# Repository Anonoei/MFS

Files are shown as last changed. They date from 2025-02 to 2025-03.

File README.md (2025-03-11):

# MFS
 Modular Filament Shelf

 

## Features
 - Expandable, just print more sides
 - Optionally secured with bolts
 - Fits spools and spool boxes

## BOM (per full side)
 All hardware is optional (except rods), and helps secure the pieces together
- 4x 5/16" rods, length by preference, designed around 1000mm
- 18x M3 heatsets
- 8x M3 nuts
- An M3 bolt for each fastner (26x)
- Printed Parts
  - Thin
    - [foot_x2](https://raw.githubusercontent.com/Anonoei/MFS/refs/heads/main/STLs/MFS-thin_foot_x2.stl)
    - [horizontal-left_x2](https://raw.githubusercontent.com/Anonoei/MFS/refs/heads/main/STLs/MFS-thin_horizontal-joint_left_x2.stl)
    - [horizontal-right_x2](https://raw.githubusercontent.com/Anonoei/MFS/refs/heads/main/STLs/MFS-thin_horizontal-joint_right_x2.stl)
    - [vertical-bottom_x2](https://raw.githubusercontent.com/Anonoei/MFS/refs/heads/main/STLs/MFS-thin_vertical-joint_bottom_x2.stl)
    - [vertical-top_x2](https://raw.githubusercontent.com/Anonoei/MFS/refs/heads/main/STLs/MFS-thin_vertical-joint_top_x2.stl)
    - [rod-joint_x2](https://raw.githubusercontent.com/Anonoei/MFS/refs/heads/main/STLs/MFS-thin_rod-joint_x4.stl)
  - Normal
    - [foot_x2](https://raw.githubusercontent.com/Anonoei/MFS/refs/heads/main/STLs/MFS_foot_x2.stl)
    - [horizontal-left_x2](https://raw.githubusercontent.com/Anonoei/MFS/refs/heads/main/STLs/MFS_horizontal-joint_left_x2.stl)
    - [horizontal-right_x2](https://raw.githubusercontent.com/Anonoei/MFS/refs/heads/main/STLs/MFS_horizontal-joint_right_x2.stl)
    - [vertical-bottom_x2](https://raw.githubusercontent.com/Anonoei/MFS/refs/heads/main/STLs/MFS_vertical-joint_bottom_x2.stl)
    - [vertical-top_x2](https://raw.githubusercontent.com/Anonoei/MFS/refs/heads/main/STLs/MFS_vertical-joint_top_x2.stl)
    - [rod-joint_x2](https://raw.githubusercontent.com/Anonoei/MFS/refs/heads/main/STLs/MFS_rod-joint_x4.stl)

### Breakdown
 - M3 heatsets (voron spec)
   - 18x total
     - rod-joint (x4)
       - 2x vertical -> rod-joint
       - 2x horizontal -> rod-joint
     - rod-joint foot (x2)
       - 2x foot -> rod-joint
     - horizontal (x2)
       - 1x horizontal left -> right
 - M3 nuts
   - 8x total
     - per rod (x4)
       - 2x, rod-joint -> rod

## Assembly
 The file number at the end indicates quantity for **one** shelf side, with two heights
 - `rod-joint` (x4): Corner pieces that also connect the `vertical-joint` and `horizontal-joint`
   - Each piece that connects to the `rod-joints` can be secured with 2x M3 bolts, and 2x M3 heatsets
   - Inside the slot, M3 nuts can be pressed in to use a bolt to secure the rod
     - there are 2x holes to allow two rods to be inserted and the shelf expanded
 - `vertical-joint` [top & bottom] (x2): Connects `rod-joints` vertically
   - `top` (1x female 1x male slot) can take 2x heatsets to lock it to bottom
   - Both are are secured using M3 bolts to M3 heatsets on `rod-joint`
 - `horizontal-joint` [left & right] (x2): Connects `rod-joints` horizontally
   - `right` (2x male) can take 1x heatset to lock it to left
   - Both are secured using M3 bolts to M3 heatsets on `rod-joint`
 - `foot` (x2): Bottom piece to ensure open spools don't touch the ground
   - Each foot is secured using M3 bolts to M3 heatsets on `rod-joint`

## Print settings
 - Layer height: 0.2
 - Nozzle: 0.4
 - Material: PLA

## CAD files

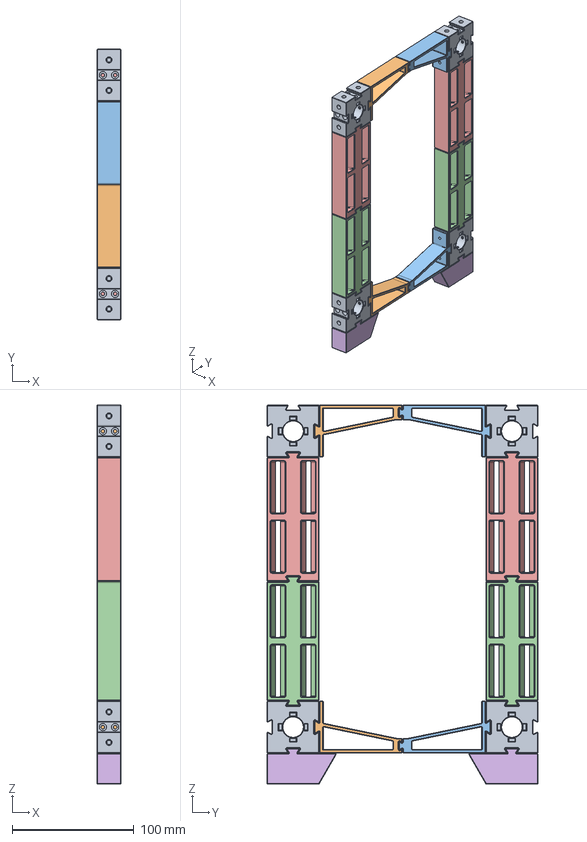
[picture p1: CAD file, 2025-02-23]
CAD/MFS-thin Side.step
20.0 x 222.8 x 311.8 mm
Rod Joint x 4
Horizontal Joint x 2
Vertical Joint x 2
Feet x 2

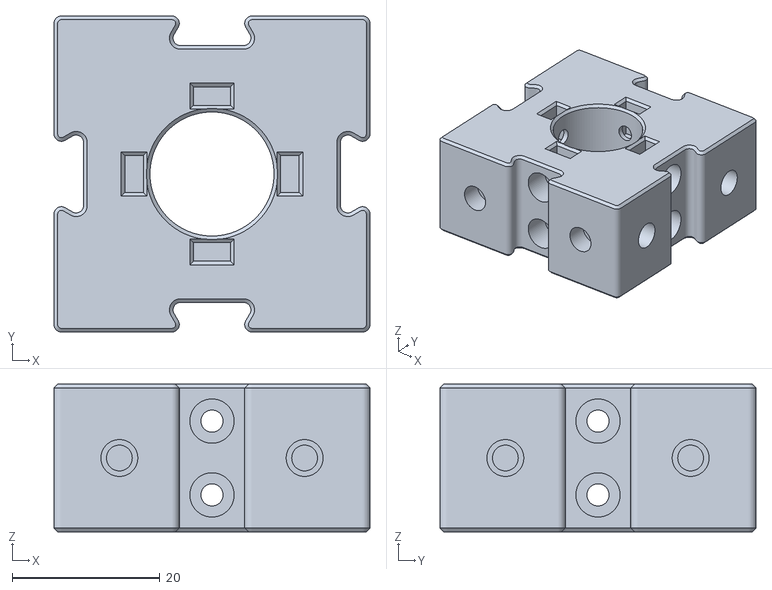
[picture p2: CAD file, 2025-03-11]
STLs/MFS-thin_rod-joint_x4.stl
42.8 x 42.8 x 20.0

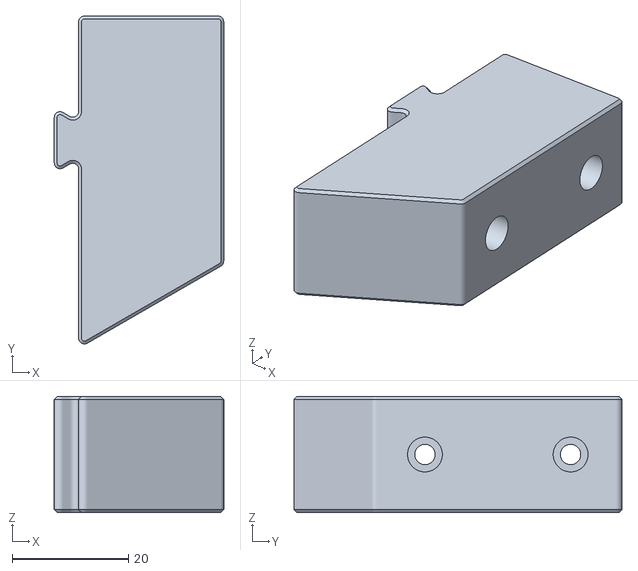
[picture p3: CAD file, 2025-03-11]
STLs/MFS-thin_foot_x2.stl
29.2 x 56.5 x 20.0

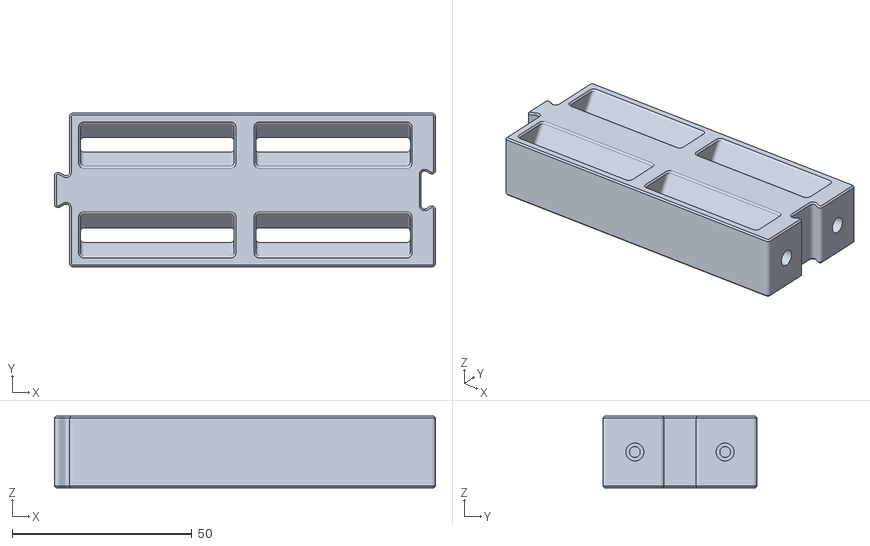
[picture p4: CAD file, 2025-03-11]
STLs/MFS-thin_vertical-joint_top_x2.stl
105.9 x 42.8 x 20.0

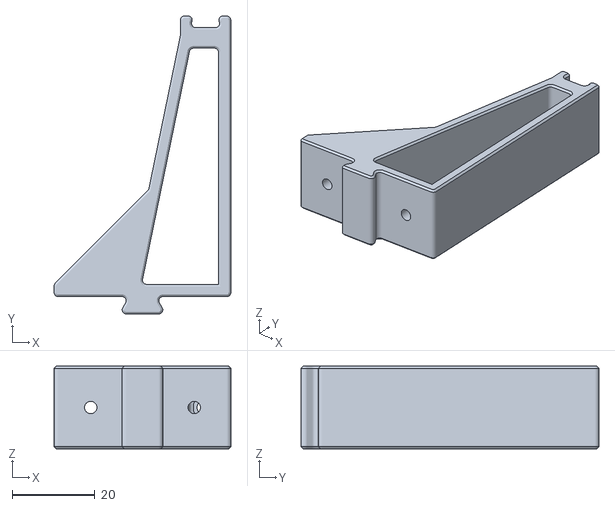
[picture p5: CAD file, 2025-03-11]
STLs/MFS-thin_horizontal-joint_left_x2.stl
42.8 x 72.2 x 20.0

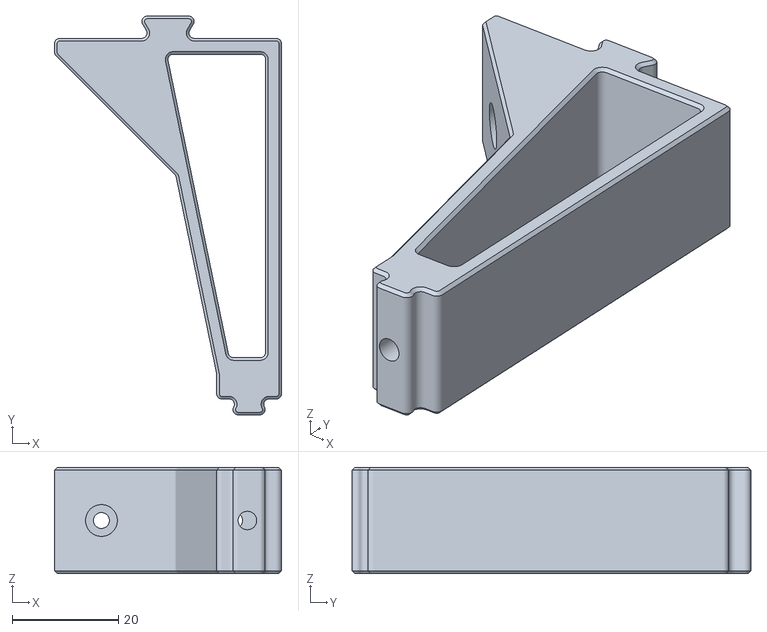
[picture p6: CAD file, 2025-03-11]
STLs/MFS-thin_horizontal-joint_right_x2.stl
42.8 x 75.2 x 20.0

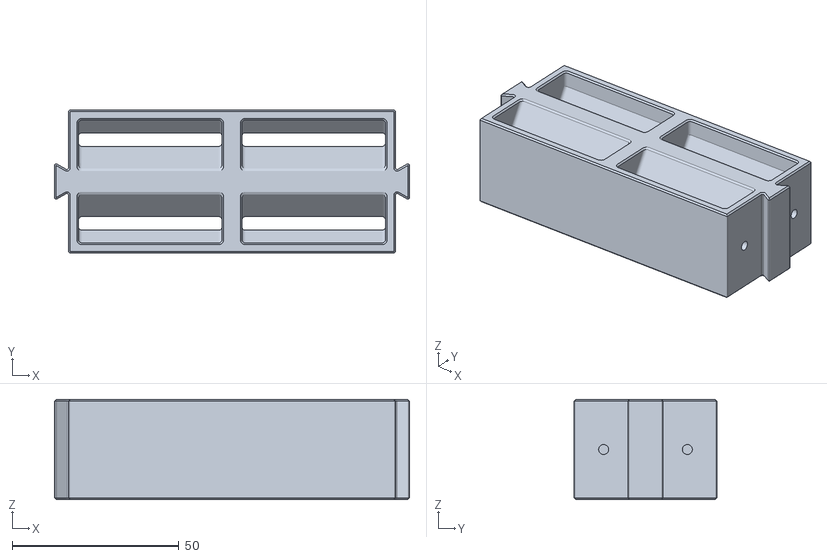
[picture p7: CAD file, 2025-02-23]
STLs/MFS_vertical-joint_bottom_x2.stl
106.3 x 42.8 x 30.0

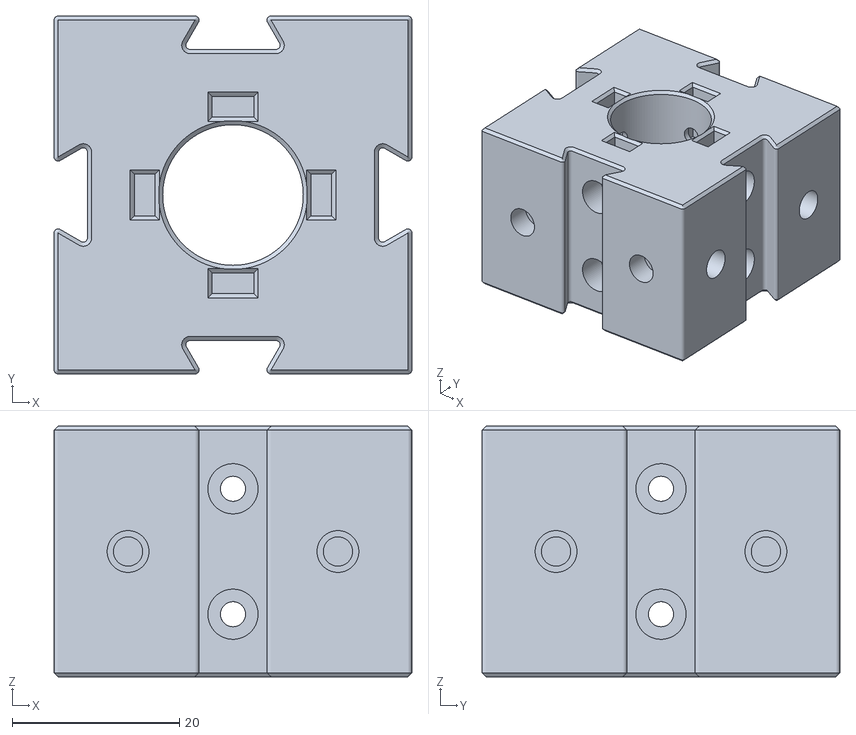
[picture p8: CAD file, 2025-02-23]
STLs/MFS_rod-joint_x4.stl
42.8 x 42.8 x 30.0

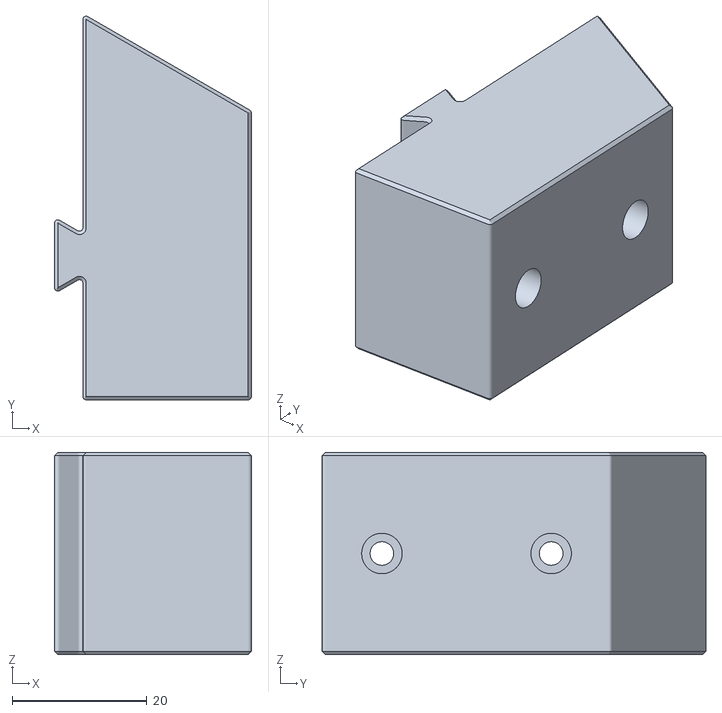
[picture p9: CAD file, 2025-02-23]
STLs/MFS_foot_x2.stl
29.2 x 56.9 x 30.0

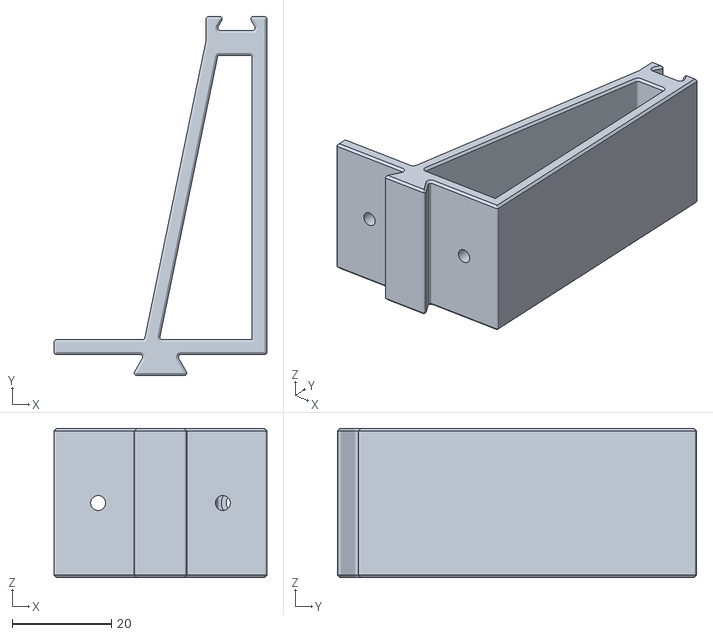
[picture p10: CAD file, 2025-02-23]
STLs/MFS_horizontal-joint_left_x2.stl
42.8 x 72.2 x 30.0

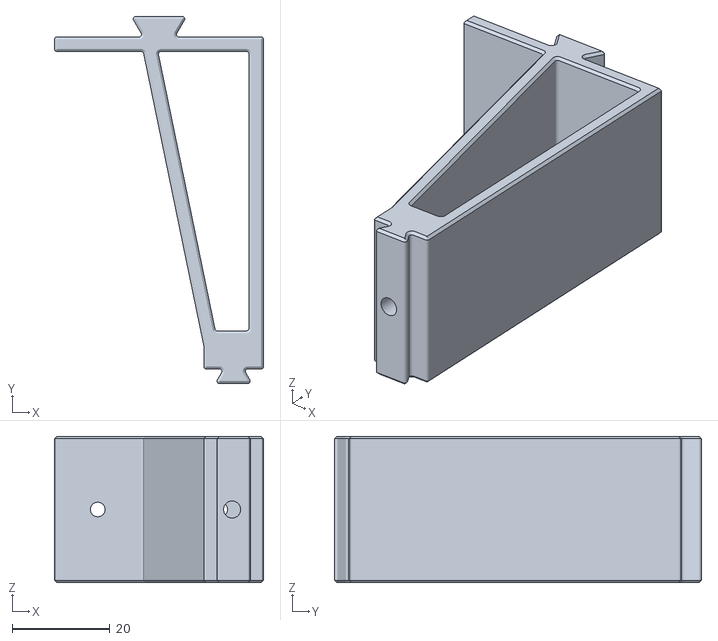
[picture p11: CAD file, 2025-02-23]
STLs/MFS_horizontal-joint_right_x2.stl
42.8 x 75.2 x 30.0

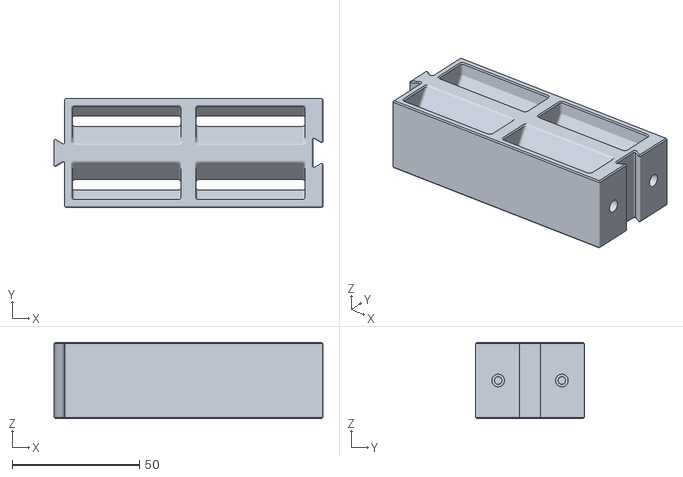
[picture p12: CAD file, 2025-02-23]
STLs/MFS_vertical-joint_top_x2.stl
105.9 x 42.8 x 30.0

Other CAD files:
STLs/MFS-thin_vertical-joint_bottom_x2.stl

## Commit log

2025-03-11 Add STL downloads to README
2025-03-11 Change fillet to 1mm from 0.5mm
    [MFS-thin_foot_x2.stl, MFS-thin_horizontal-joint_left_x2.stl, MFS-thin_horizontal-joint_right_x2.stl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]
